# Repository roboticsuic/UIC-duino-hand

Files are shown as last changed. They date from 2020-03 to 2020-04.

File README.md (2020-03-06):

# UICduinohand
Project of the prosthetic hand:

_Objectives_: 
- Learn the basics of 3D printing and electronics in order to create a prostheic hand controlled with the Cthulhu Shield sensor.
- Use motors and electronic devices in order to understand its functions.

_Materials_:
- **For 3D printing**:
  - PLA for the entire hand except the junctions that are of TPU.
  - Ultimaker 2+.
  - Sandpaper.
- **For the electronics of the hand**:
  - Arduino MKR 1000 WIFI.
  - Servo motors.
  
_Definitions_:

**MKR 1000 WIFI**:
- Price: €26.50 [https://store.arduino.cc/arduino-mkr1000-wifi].
- Size: Length 61.5mm Width 25mm.
- Weight: 32gr.
- Microcontroller: SAMD21 Cortex-MO + 32bit low power ARM MCU.
- Board Power Supply (USB/VIN): 5V.
- Supported Battery: Li-Po single cell, 3.7V, 700mAh minimum.
- Circuit Operating Voltage: 3.3V
- Digital I/O Pins: 8.
- PWM Pins: 12 (0,1,2,3,4,5,6,7,8,10,A3 -or 18 -, A4 -or 19).
- UART: 1.
- SPI: 1.
- 12C: 1.
- Analog Input Pins: 7 (ADC 8/10/12 bit).
- Analog Output Pins: 1(DAC 10 bit).
- External Interrupts: 8(0,1,4,5,6,7,8,A1 -or 16-, A2 - or 17).
- DC current per I/O Pin: 7mA.
- Flash Memory: 256KB.
- SRAM: 32KB.
- EEPROM: no.
- Clock Speed: 32.768kHz (RTC), 48MHz.
- LED_BUILTIN: 6.
- Full-speed USB Device and embedded Host.

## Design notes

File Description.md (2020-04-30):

# UICduinohand 
## PROJECT: **Prosthetic hand controlled by a tongue sensor**
This project is based on the manufacture of a prosthetic hand, a device designed to help those with loss of hand and forearm to retain the function and appearance of the missing section. Here we intend to report on how we created an electric prosthetic hand that has a set of fully articulated fingers. The wearer can manipulate the hand by moving a specific part of their body, in this case the tongue. It is a very innovative project because through a tongue sensor, which has built-in electrodes that show the signals of the tongue tactilely, we connect it to a 5V Arduino plate allowing to activate a movement of our prosthetic hand as it is the clamping (hand close and open).
The project is developed on the basis of a previous project that we found in thingiverse (https://www.thingiverse.com/thing:797558), where we got the hand model that we decided to print in 3D.

_Objectives_: 
- Learn the basics of 3D printing and electronics in order to create a prosthetic hand controlled with the Cthulhu Shield sensor.
- Use motors and electronic devices in order to understand its functions.

_Materials_:
- **For 3D printing**:
  - PLA (for the most solid structures; PLA has good tensile strength, rigid and a detailed and glossy surface quality)
  - TPU (for the junctions; TPU has a great flexibility and an excellent impact to resistance)
  - Ultimaker 2+ (3D printer)
  - Sandpaper
- **For the electronics of the hand**:
  - Arduino MKR 1000 WIFI
  - Servo motor "9g"
  - Cthulhu Shield sensor
  - Arduino cables
  - Straw / 3D printed tube
  - Fishing line
- **Softwares**:
  - Unity 3D (to create animations and represent how the prosthetic hand works)
  - SolidWorks (to create some pieces that we need)
  - Ultimaker Cura (to adjust setting parameters of the 3D printer)

_Definitions_:

**MKR 1000 WIFI**:
- Price: €26.50 [https://store.arduino.cc/arduino-mkr1000-wifi].
- Size: Length 61.5mm Width 25mm.
- Weight: 32gr.
- Microcontroller: SAMD21 Cortex-MO + 32bit low power ARM MCU.
- Board Power Supply (USB/VIN): 5V.
- Supported Battery: Li-Po single cell, 3.7V, 700mAh minimum.
- Circuit Operating Voltage: 3.3V
- Digital I/O Pins: 8.
- PWM Pins: 12 (0,1,2,3,4,5,6,7,8,10,A3 -or 18 -, A4 -or 19).
- UART: 1.
- SPI: 1.
- 12C: 1.
- Analog Input Pins: 7 (ADC 8/10/12 bit).
- Analog Output Pins: 1(DAC 10 bit).
- External Interrupts: 8(0,1,4,5,6,7,8,A1 -or 16-, A2 - or 17).
- DC current per I/O Pin: 7mA.
- Flash Memory: 256KB.
- SRAM: 32KB.
- EEPROM: no.
- Clock Speed: 32.768kHz (RTC), 48MHz.
- LED_BUILTIN: 6.
- Full-speed USB Device and embedded Host.

**Servo Motor**:
- RC plane "9g" servo motor. 
- We took it from: https://grabcad.com/library/9g-servo-motor-1 (modelled and rendered in Solidworks)

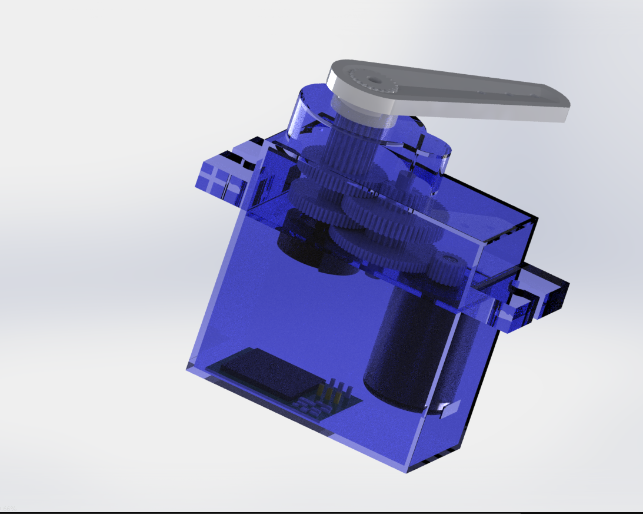
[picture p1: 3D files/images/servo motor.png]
servo-motor

- Tiny and lightweight with high output power. 
- Servo can rotate approximately 180 degrees (90 in each direction), and works just like the standard kinds but smaller. 
- You can use any servo code, hardware or library to control these servos. 
- Good for beginners who want to make stuff move without building a motor controller with feedback and gear box, specially since it will fit in small places. 
- It comes with a 3 horns (arms) and hardware.

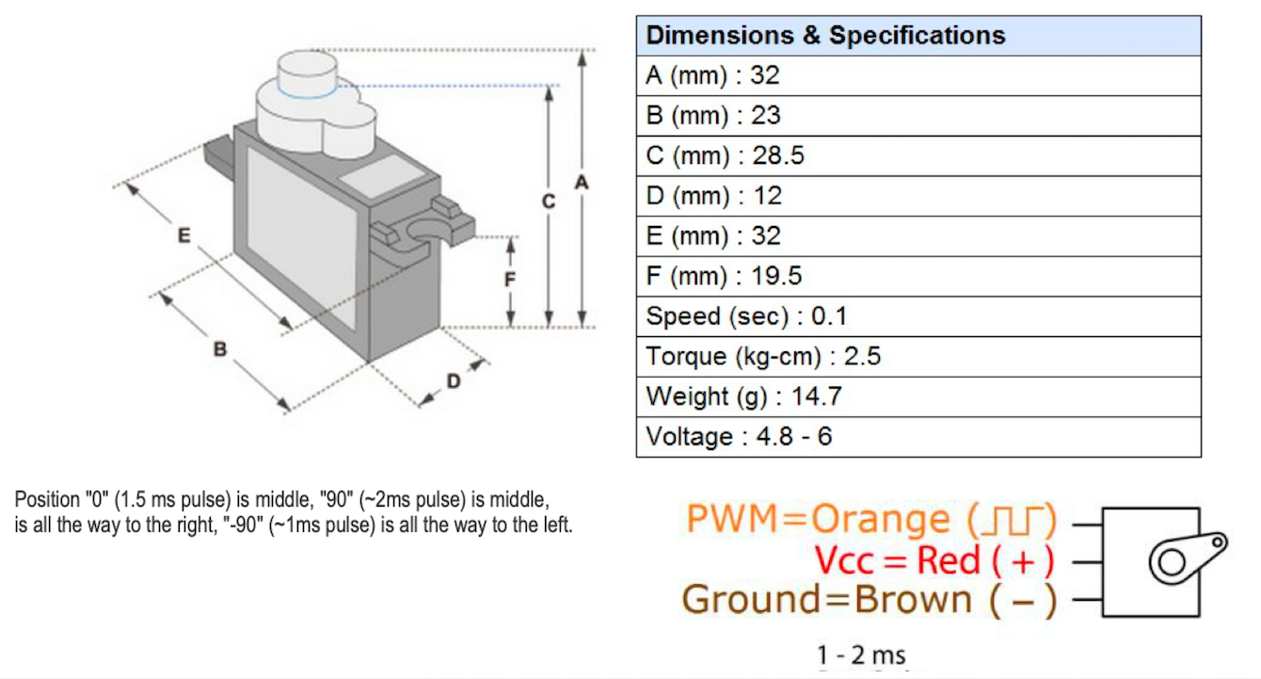
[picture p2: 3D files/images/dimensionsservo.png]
dimensionsservo

**Cthulhu Shield sensor**: 

The Cthulhu Shield is an open-source Arduino Uno compatible sensory substitution/sensory augmentation device. It uses an 18 electrode grid to tactile display signals on the tongue. The electrodes on the array can be activated with patterns of electrical pulses to depolarize nerve membranes in the tongue to create different types of touch sensations. You can use these touch sensations to draw shapes or simple images on the tongue, feel different sound frequencies, or receive turn by turn directions with your tongue.
Additionally, the Cthulhu Shield can sense whether or not your tongue is in contact with different electrodes using capacitive sensing. You can use the Cthulhu Shield to send keystrokes to your computer, control the cursor, or even control a mobility device.

Good video explanation: https://www.youtube.com/watch?time_continue=197&v=wd38Go9tbds&feature=emb_title

_Results_:

For this project, we just wanted to create a movement of close/open the hand, therefore with one servo we have enough to move all the fingers at the same time. However, as the fingers are in different positions we need to use a straw or a 3D printed tube (_depending on the circumstances of the quarantine, because the best option is a 3D printed tube because offers better resistance, but if we are not able to use the 3D printer of the lab then a straw is also useful_) to guide the fishing line of each finger to the servo motor.

We decided to use the same thread material that is used in fishing because is transparent (_hence give a better view of the prosthetic hand_) and offers better elasticity than others. Moreover, the length of the fishing line needed depends on the size of your prosthetic hand, in our case we will need --- cm.

On the other side, to distribute the motor servos, the Arduino MKR and the guide tubes inside the box of the prosthetic hand, we have plenty of options, for example: use a vertical servo and a drum to role the thread, use a vertical servo and a gripper... But due the design of the box we had limitations in which option to choose, hence the option that we choosed is to use a horitzontal servo (_because the height of the box is not high enough_) that goes from 0-180 degrees with a guide tube. See the image bellow:

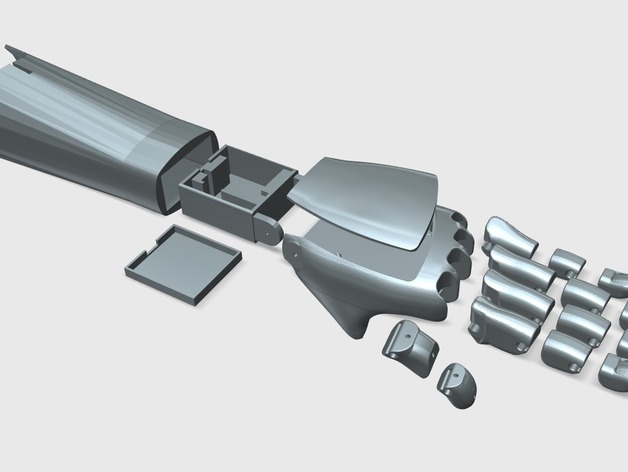
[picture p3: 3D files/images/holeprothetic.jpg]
hole hand ensambled


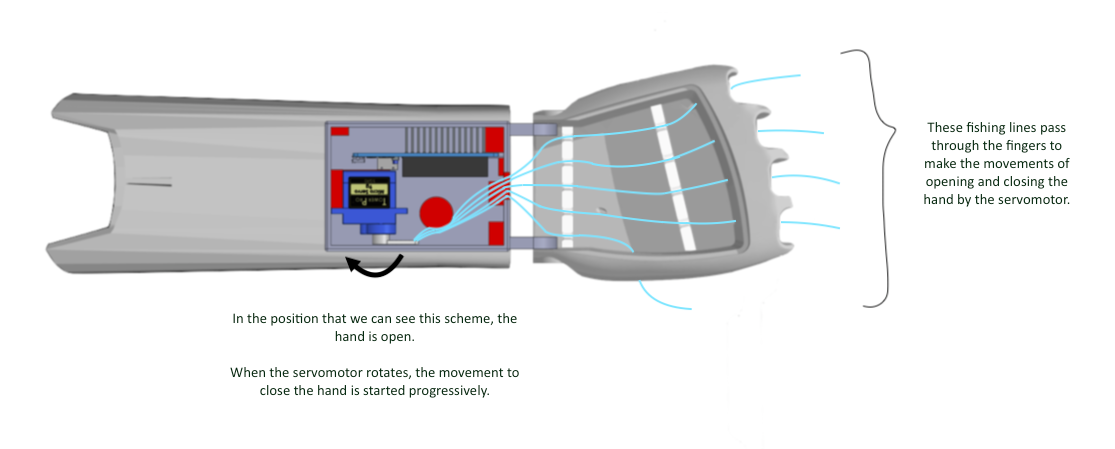
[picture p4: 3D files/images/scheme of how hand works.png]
scheme of how hand works


Doing reference to the code and the scheme, the code is designed to be able to maintain a certain position of the hand until the MKR recieve a new input to change the position, in that way, we avoid the patient to exercise compression force in the Cthulhu constantly generating fatigue. To continue as we don't have in thinkercad nor in physic the Cthulhu sensor, we used two buttons to simulate the Cthulhu sensor function of closing and opening the prosthetic hand.

With this code our aim is to control a servo motor with 2 buttons that simulate the Cthulhu sensor function. In this case, one button is to move the hand from 0º to 180º (to open the hand) and the other one is to move the hand from 180º to 0º (to close the hand). In the case of the Cthulhu sensor, one electrode will be to open the hand and another to close it. 

Now, we are going to explain the **schematic image** which shows the connection of the Arduino with the electronic elements:

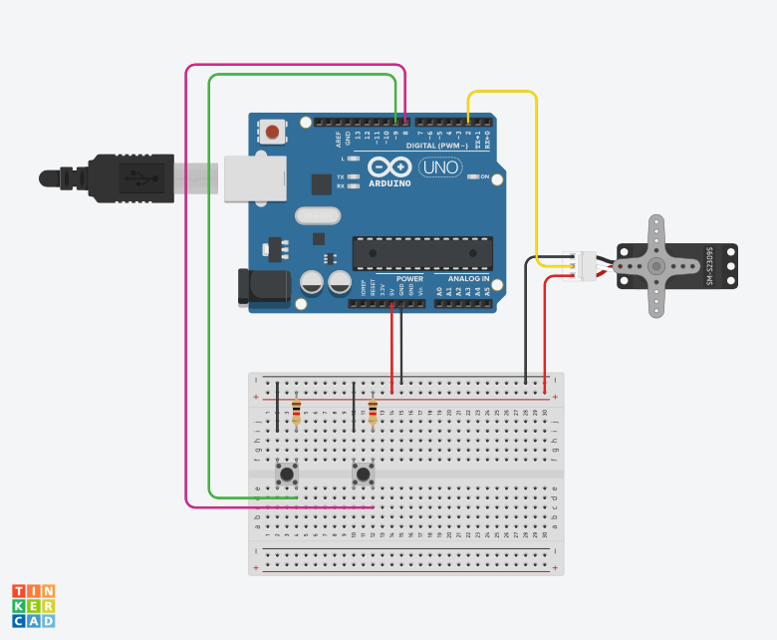
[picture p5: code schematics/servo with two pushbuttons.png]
servo with two pushbuttons


  - As we can see, the 5V is connected to the positive pole of the servo as a supplying power. 
  - The ground (GND) is connected to the ground black cable as a reference to all other electronic parts, where the electrical level is at 0 V. 
   - The other cable is the signal to move the servo motor to the required angle, that signal corresponds to a PWM (Pulse Width Modulation, a technique for getting analog results with digital means). This cable is connected to the pin 2. 

Then, we have to connect the 2 buttons and 2 resistances for increasing or decreasing the angle. Negative poles are connected to GND and positive ones are connected to pins 8 and 9 with a resistance respectively. 

Regarding the **code**: 

At first, we have to implement the _Servo.h_ library and we have declared the function Servo called as _mi_servo_. 
Then, we declare 3 variables integer. The first one indicates the initial position (which in this case is 0º) and the second and third ones refers to the buttons that increase or decrease the angle.

After this, _void setup_ is used to configure the initial parameters:
    - _mi_servo.attach (2,750,1800)_: We use the attach function to attach the servo variable to a pin, where 2 refers to the pin 2 connected to the servo. In PWM, 750 ms represents 0º and 1800 ms represents 180º. It is a conversion from servo pulses to degrees.
   - Then, we configure the input pins with _pinMode_.
   - Initialize your servo motor with the function ’’.write’’, in this case it will move 90º.

In the _void loop_, we have 2 conditions ‘’if’’.
- _digitalRead_ function: It asks for the pin 8 and it is activated with a LOW state. And with ‘grados++’ you start increasing the degrees. The following condition if is to protect the servo motor, it is a condition for the motor to not exceed the 180º.

- The second big condition is the same but it corresponds to the pin9, and ‘grados - -' reduces the degrees. And the following condition guarantee to get to 0º and to not exceed it. 
- _mi_servo.write(grados)_: It writes a new angle in degrees.
- _delay(10)_; It is used to write between degrees and present a good lecture in Arduino and the servo.

In **SolidWorks**, a computer assisted design software to model 3D parts and assemblies and 2D plans, we mainly use it to take measurements of some parts to be able to think how we would put all the electronic part. Once we decided that we were going to use only one servo and specifically the model chosen, we had to modify the box where we put the electronics to optimize the space and put an arduino mkr (although the use of smaller arduinos to control servos would be a more suitable option). Also with Solidworks we design a inner guide of the box and a hole hiding to route the lines and to make them not entangled between themselves when they are pulled by the servo, to make the movement of closing the hand and then the movement of opening. 
Once we had all the pieces that we need, we adjusted the printing settings with Ultimaker Cura and finally we printed all the pieces with _Ultimaker 2+_.

  _Printing setting for PLA_:
  - Extruder temperature: 180ºC - 210ºC
  - Cooling fan: 100%
  - Min. layer height: 0.08 - 0.2mm
  - Bed. temperature: 60ºC
  - Speed: 40 - 80mm/s → For hand and arm printing we reduced the speed to 20mm/s as these were larger pieces and we wanted to avoid bad cooling.
  - Support: not needed
  - Top/Bottom pattern: ZigZag
  
  _Printing setting for TPU_:    
  - Extruder temperature: 220ºC - 260ºC
  - Cooling fan: without
  - Min. layer height: ≥0.1mm
  - Bed temperature: 40ºC
  - Speed: 15 - 40mm/s
  - To print TPU we have to store it in an airtight container with desiccant Dry filament before printing.
  
For a better final result of the 3D printed pieces we used sandpaper to polish them. 

With **Unity**, we tried to do to a real-time visualization of how the prosthetic hand works. This involved the use of the real-time engine of Unity linked with 3D rigging programs (in this case Blender was the idea). The idea was to open and close the animated hand depending on the input of the Arduino program mentioned avobe. Due to limited knowledge on Unity and some technical problems, finally, this couldn't be accomplished. Instead a 3D view of the completed hand has been done in Blender to show the final result of the prosthetics: 

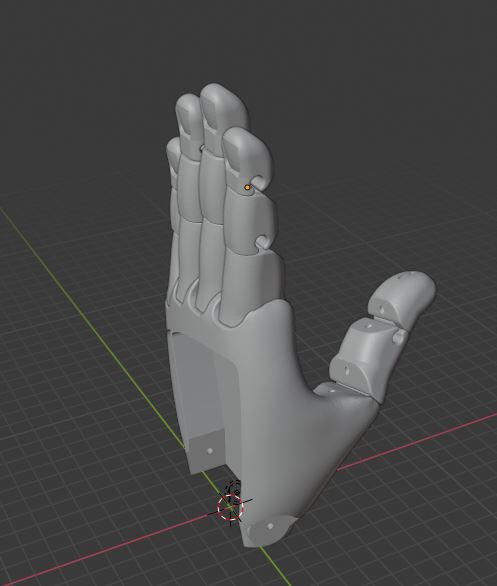
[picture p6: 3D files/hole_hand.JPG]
hole_hand


_Conclusions_:

We could conclude this project by saying that we have learned different variables to take into account when creating a prosthesis. We have been able to program with Arduino, seeing how we must create the circuit and the code, facing the circumstances that we had, simulating with buttons the function of the sensor to close and open the hand. And we have put the design into practice, whether it is at the level of computer aided design for 3D mechanical modeling, or for creating virtual reality visualizations.
On the other hand, talking about what we are trying to replace, in this case the hand, we saw that it has many movements, of which we have focused only on recreating one of them. As a future project, we think it would be great to be able to incorporate more and more movements, perhaps progressively, to give those who require the prosthesis a high degree of freedom.
Also we have been able to see that the language sensor we have used in the project can have many uses, including the development of sensory substitution. It is very interesting to contemplate the idea that sensory substitution tools and techniques take the sensory information normally received in one organ can be presented in another way to another sensory organ. So we would be talking about recovering the sensory information that has been lost, and learning to process it through another organ.

Most importantly, we believe that the **simplest human happiness comes from physical activity**, and we have been able to provide an option to reclaim it.

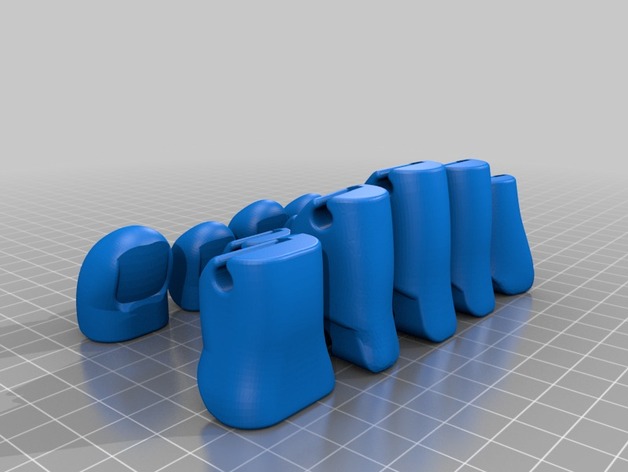
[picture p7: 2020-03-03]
3D files/images/finger.jpg

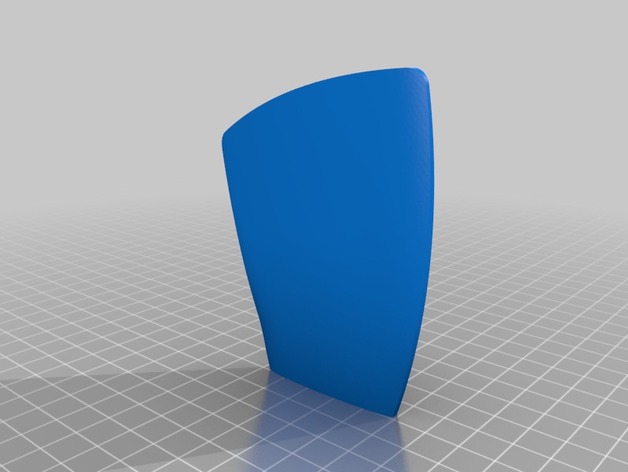
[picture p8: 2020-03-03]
3D files/images/cover2.jpg

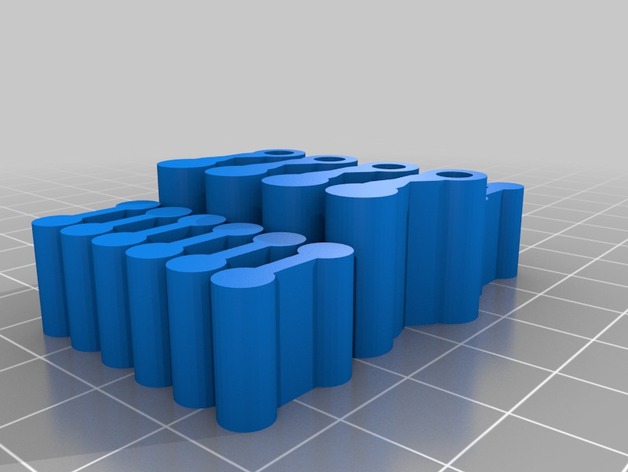
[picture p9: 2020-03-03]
3D files/images/fingerjoints.jpg

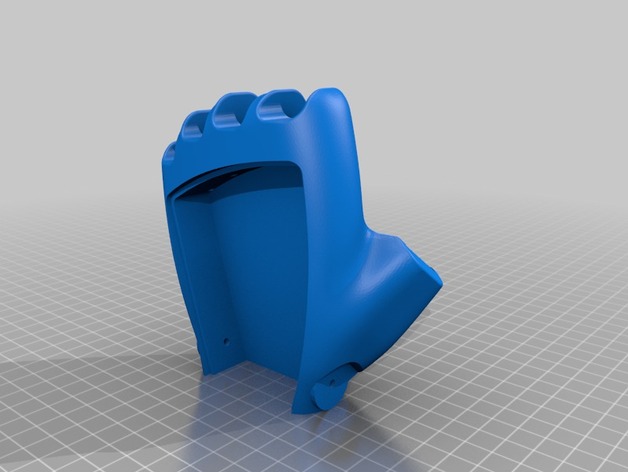
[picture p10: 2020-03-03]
3D files/images/hand1.jpg

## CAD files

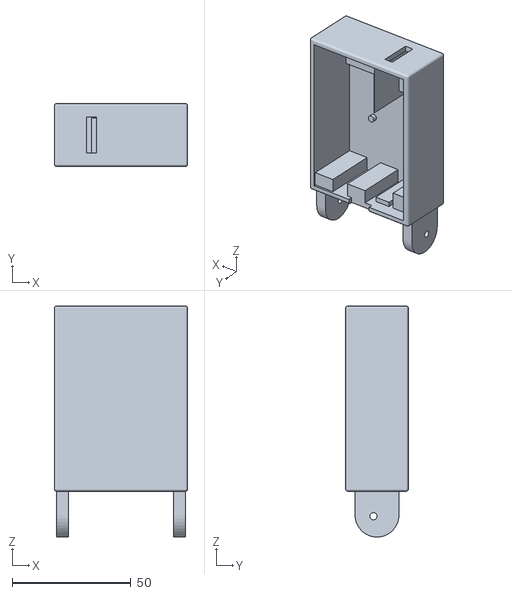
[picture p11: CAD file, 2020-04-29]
3D files/servo housingMain.STL
56.1 x 26.5 x 97.2

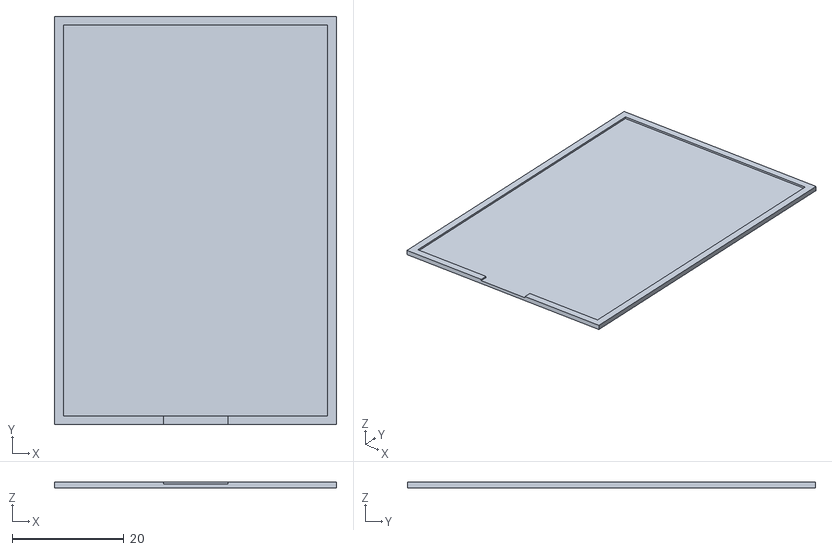
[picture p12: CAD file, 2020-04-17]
3D files/ServoHousingCoverMain.STL
50.4 x 73.0 x 1.00

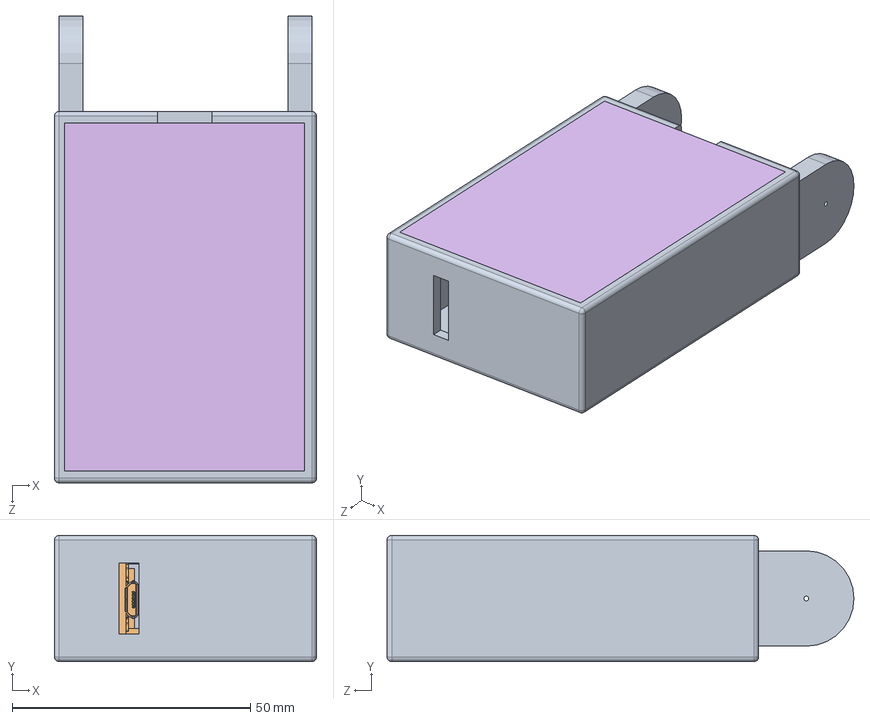
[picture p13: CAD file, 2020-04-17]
3D files/Solidworks Files/BoxAssembly.SLDASM
55.0 x 26.5 x 98.0 mm
modified servo housing
ArduinoMKR1000 usedforassembly
SG90 BODYusedforassembly
SG90 ARMusedforassemblye
Inner guide of the box
BoxCover

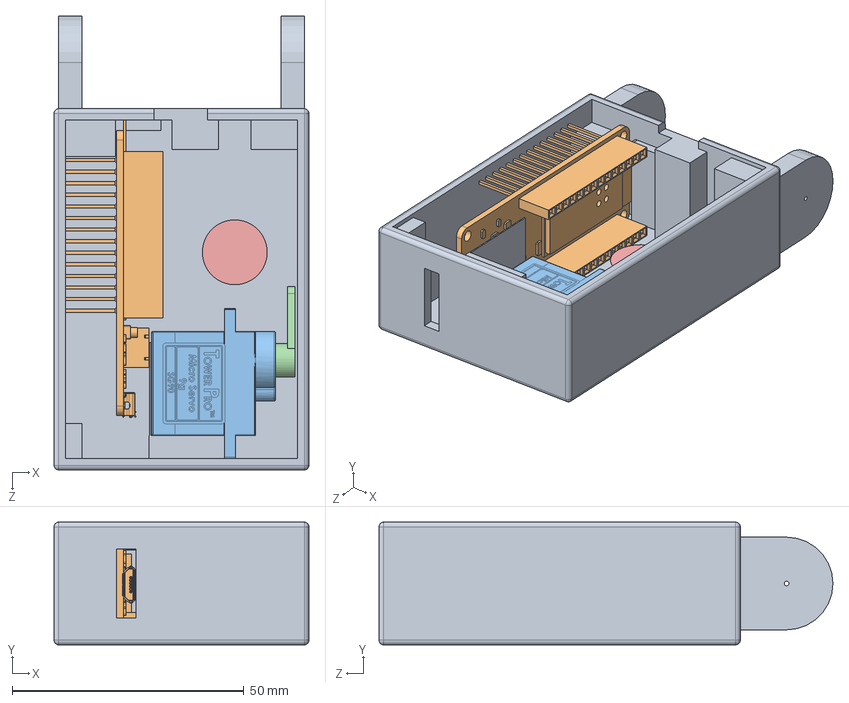
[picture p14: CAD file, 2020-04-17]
3D files/Solidworks Files/Box Assembly without a cover.SLDASM
55.0 x 26.5 x 98.0 mm
modified servo housing
ArduinoMKR1000 usedforassembly
SG90 BODYusedforassembly
SG90 ARMusedforassemblye
Inner guide of the box

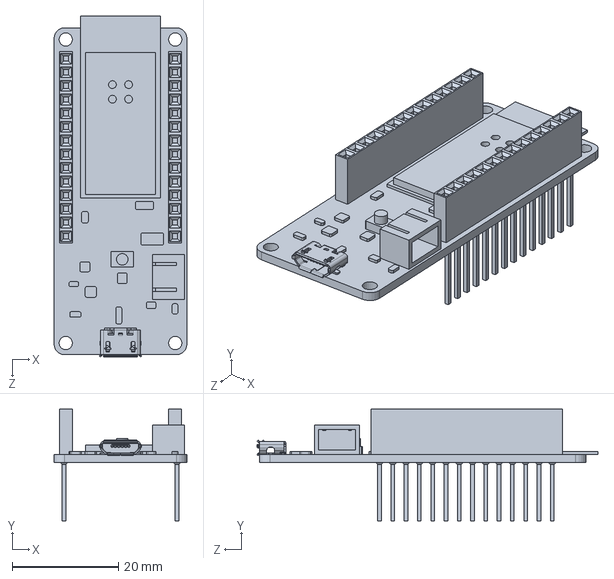
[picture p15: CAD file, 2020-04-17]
3D files/Solidworks Files/ArduinoMKR1000 usedforassembly.SLDPRT
25.0 x 21.0 x 64.1 mm

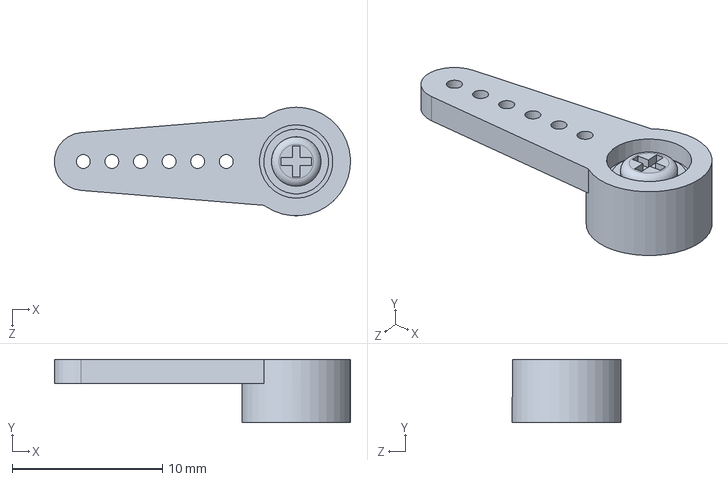
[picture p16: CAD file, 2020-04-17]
3D files/Solidworks Files/SG90 ARMusedforassemblye.SLDPRT
19.7 x 4.23 x 7.24 mm

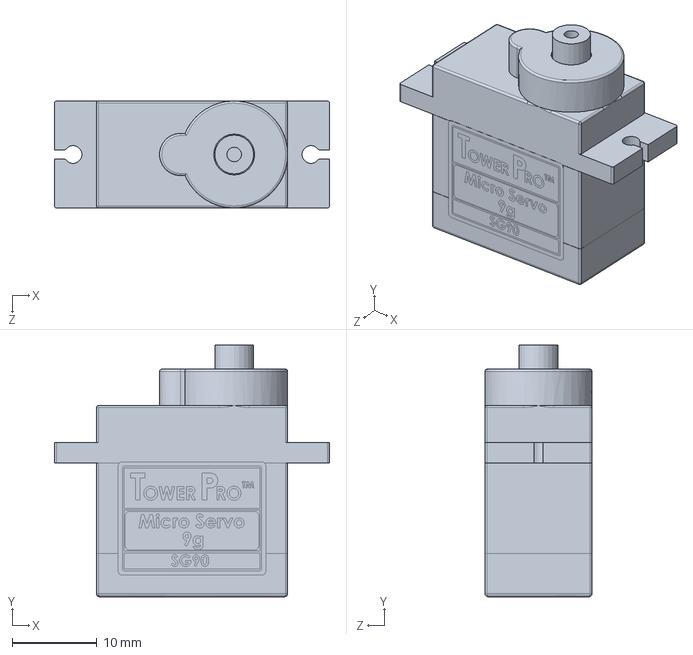
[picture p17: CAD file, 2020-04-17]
3D files/Solidworks Files/SG90 BODYusedforassembly.SLDPRT
32.4 x 29.6 x 12.6 mm

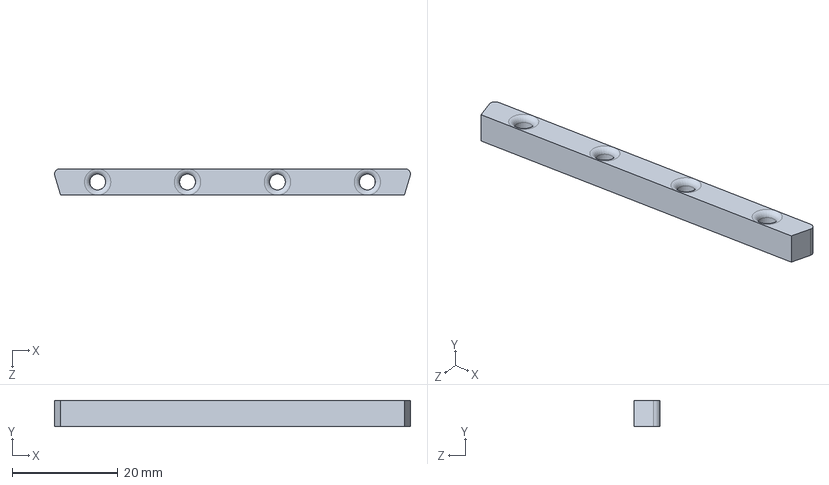
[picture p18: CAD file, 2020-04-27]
3D files/Solidworks Files/4-hole guide.SLDPRT
67.3 x 5.00 x 5.00 mm

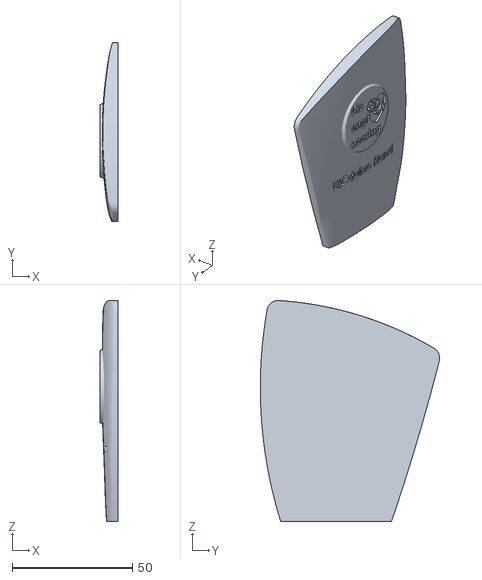
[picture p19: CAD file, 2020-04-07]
3D files/Placa con logo.STL
7.55 x 74.6 x 92.0

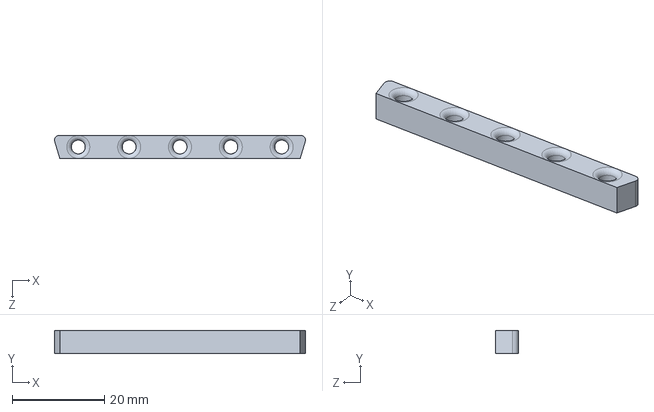
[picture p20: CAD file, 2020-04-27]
3D files/Solidworks Files/5-hole guide.SLDPRT
54.3 x 5.00 x 5.00 mm

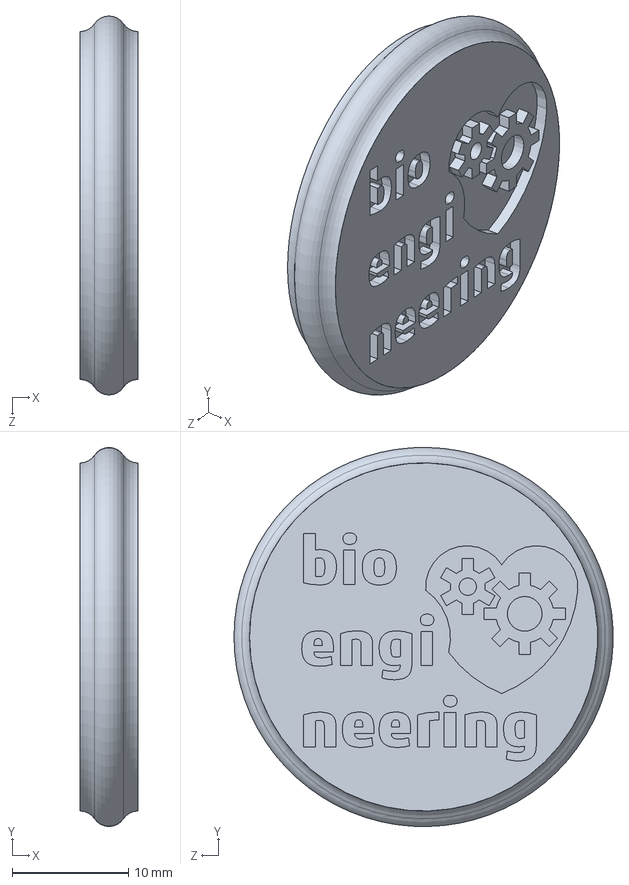
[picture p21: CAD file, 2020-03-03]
3D files/logo example.SLDPRT
5.00 x 32.7 x 32.7 mm

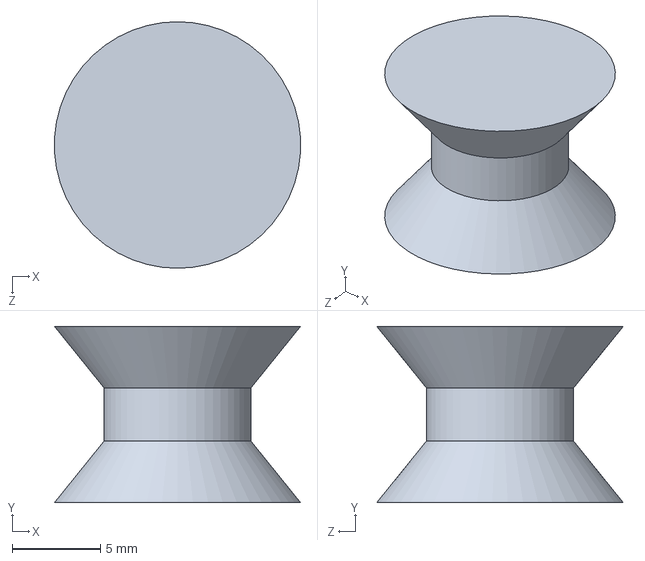
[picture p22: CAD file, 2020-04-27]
3D files/Solidworks Files/Inner guide of the box.SLDPRT
14.0 x 10.0 x 14.0 mm

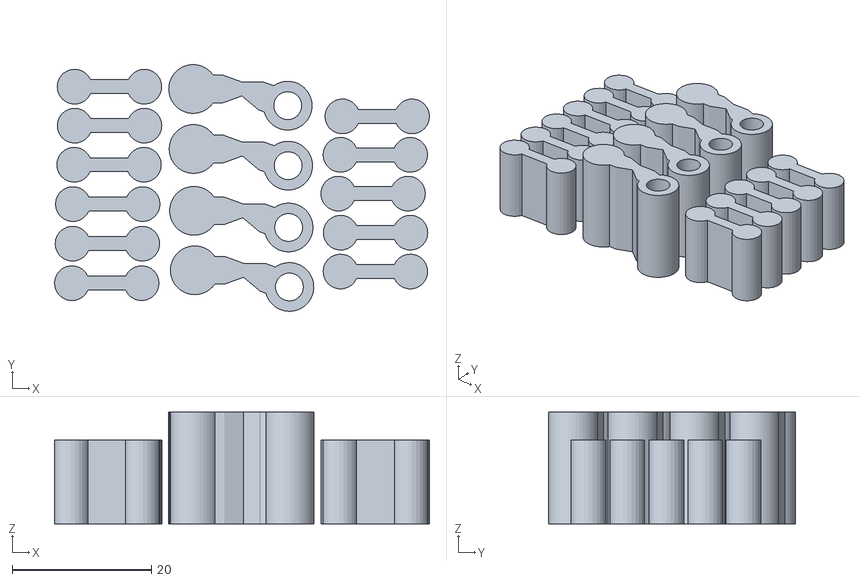
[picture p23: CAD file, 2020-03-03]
3D files/FunMove_Finger_Joint.stl
53.8 x 35.4 x 16.0

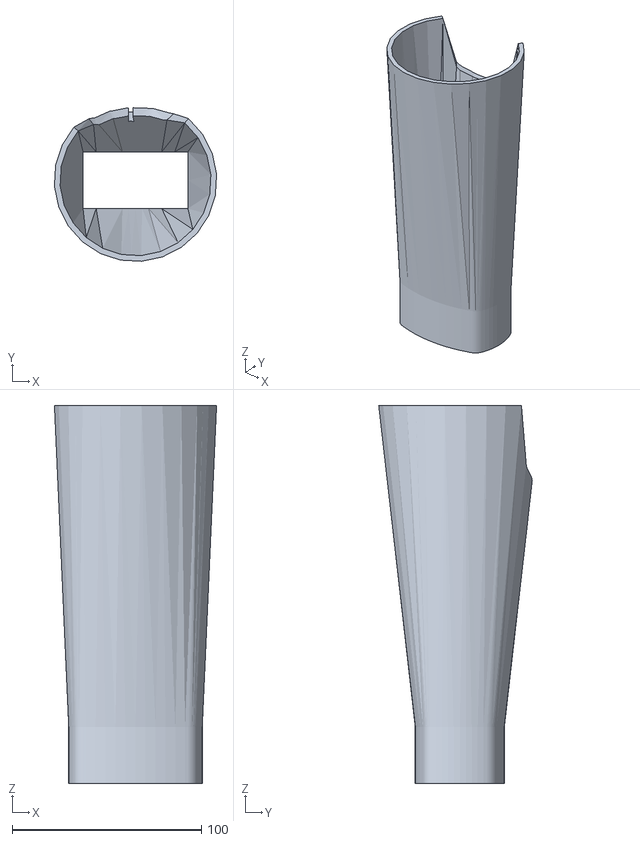
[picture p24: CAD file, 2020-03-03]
3D files/FunMove_Gun_KKB.stl
85.8 x 81.3 x 200.0

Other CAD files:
3D files/Solidworks Files/modified servo housing.SLDPRT
3D files/Solidworks Files/BoxCover.SLDPRT
3D files/Arduino MKR1000 STL.STL
3D files/LH_Finger_Plate.stl
3D files/4-hole guide.STL
3D files/5-hole guide.STL
3D files/Inner guide of the box.STL

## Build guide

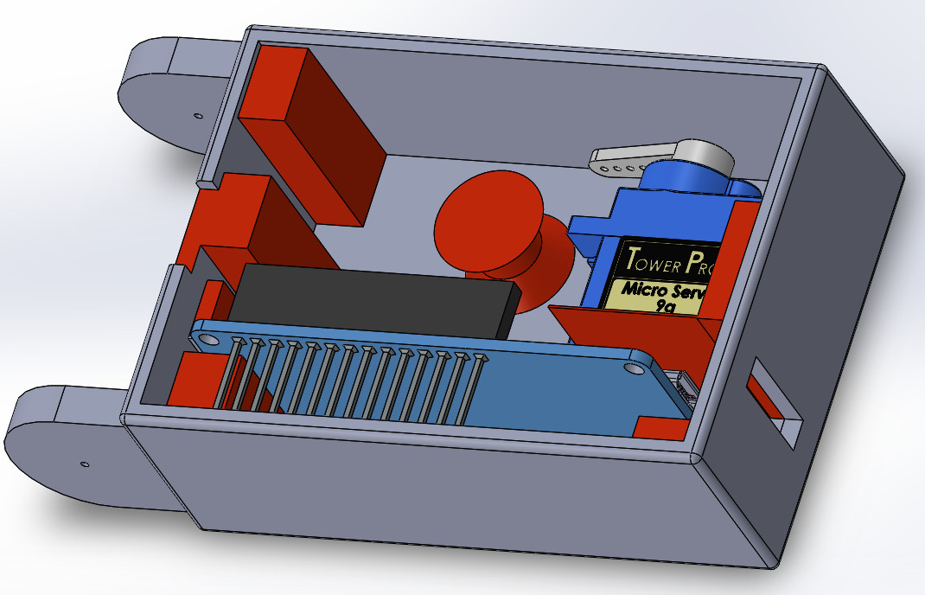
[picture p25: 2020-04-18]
3D files/images/scheme box ensamble view 2.PNG

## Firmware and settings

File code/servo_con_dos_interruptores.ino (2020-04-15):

#include <Servo.h>        //Implement Servo library
Servo mi_servo;           //Declare the Servo function

int grados= 0;            //Initialize in 0º
int suma = 8;             //Declare the button that increase the angle
int resta = 9;            //Declare the button that decrease the angle


void setup() {                         //Configure initial parameters
  
   mi_servo.attach(2,750,1800);        //Configure the servo, in this case 750ms = 0º and 1800ms = 180º 
   pinMode(suma, INPUT);               //Configure the input pins
   pinMode(resta, INPUT);
   mi_servo.write(grados);             //Move the servo until the number of degrees, in this case 0º
}


void loop() {
  
   if (digitalRead(suma) == LOW)           //Ask for 'suma' button and it is activated with a Low state, when it is at 0V (because it is normally connected at 5V)
   {
     grados++;                             //Increase degrees
     
     if (grados>180)                       //Protect the servo motor to not exceed 180º
     {
       grados=180;
     }
   } 
   if (digitalRead(resta) == LOW)          //Ask for 'resta' button and it is activated with a Low state
   {
      grados--;                            //Decrease degrees

     if (grados<=0)                        //Protect the servo motor to not decrease more than 0º
     {
       grados=0;
     }
   }
   mi_servo.write(grados);                //Write a new angle in degrees
   delay(10);                             //Delay to have a good lecture of the Servo and Arduino
}

  
